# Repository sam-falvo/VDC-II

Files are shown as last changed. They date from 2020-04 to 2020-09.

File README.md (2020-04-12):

# VDC-II
The VDC-II core is an open source Video Display Controller following in the footsteps, but not a pure clone, of the Commodore 8568 VDC chip.

Link to project on [Hackaday.io](https://hackaday.io/project/170581-vdc-ii).

## Why?
I'm working on a homebrew computer of my own design, called the Kestrel-3.
The Kestrel-3 project, however, is very slow-going, as I'm basically building everything from the ground up.
I was asked if I could instead implement the salient bits of the Kestrel-3's video core, the Configurable Graphics Interface Adapter, or CGIA, for the RC2014 backplane.
That would both speed up development of the Kestrel-3 project, as I'm more focused on individual components, but also can benefit the RC2014 community as well.
I said, "that sounds like a great idea!"

Problem is, I've never built an RC2014 or an expansion board for it before.
And, there are many unknowns along the way:
for example, I've never worked with level shifting logic before,
and interfacing a 25MHz dot-clock circuit to the 7MHz bus of the RC2014 will involve multiple clock domains and its respective complexities.
To get my feet wet, I decided to target a design for the 39-pin RC2014 expansion bus using a small FPGA part, specifically the TinyFPGA BX.

The problem with the TinyFPGA BX is that I'm severely I/O limited!
But, with careful interface design, and a constriction on the number of I/O ports accessible to the host CPU, I was able to fit everything into the pins available.
Also, the TinyFPGA BX provides 16KB of block RAM resources, and that sparked a memory: didn't the C128's VDC chip only have 16KB available to it?

Turns out, yes.  And, it also has a constrained host CPU interface as well.
And looking through the C128's Programmers Reference Manual on how to code for the VDC chip,
I saw that much of the CGIA's feature set was already present in the VDC.  Not everything, but most things for sure!
So, I got to thinking, instead of using the CGIA as the basis,
maybe I can create a version of the VDC chip which can drive a VGA monitor, flexibly.
After all,
the [RomWBW HBIOS](https://github.com/wwarthen/RomWBW/blob/master/Source/HBIOS/cvdu.asm)
software already has a VDC driver available for it, so porting software should be much easier.
(Though, strangely, it goes by the name CVDU or Color VDU in the source tree.)
That's the operating theory, at least.

The VDC-II project was born.

## Description
The VDC-II core aims to be a worthy successor to the original Commodore VDC design.
Unlike the original VDC chip, which runs at NTSC frequencies, the VDC-II core is intended to drive a VGA monitor.

While 100% backward compatibility is not my primary goal, I would continue to strive for it where I can afford to.
There will be some features which will simply work differently between the VDC and VDC-II,
such as how horizontal smooth scrolling works.
Some of these incompatibilities will stem naturally from the fact that we're driving a VGA display instead of a CGA display.
**Disclaimer: I do not have a real Commodore 128 to test behavior with.**
I'm limited to comparing behavior against what the Vice `x128` emulator supports.

## Goals
Most importantly, I want to make a VDC-II core that achieves *basic* feature parity with the original VDC.
This should include supporting all 37 of the original register set.
**Note:** Not all bits of all registers will be supported, or will work *exactly* the same way.
For example, the complex interaction between inter-character gaps and horizontal smooth scrolling might compel me to just leave inter-character gaps out of the design.
(Kind of how `x128` does now.)

Going into future day-dreaming mode,
I'd next implement color palette registers,
giving the VDC-II core more color options.
I'd also support an alternative attribute format which allows for both 16 foreground *and* background colors.

The VDC-II core could conceivably be expanded to support sprites as well, perhaps using an interface not unlike the TMS9918A VDP.
This will be very nice for, e.g., supporting mouse pointers and text cursors while in bitmapped mode (e.g., GEOS/128).

## Resources
These are some handy references and resources I've found to help guide my development.
These might be of interest to you as well.

- https://www.retrobrewcomputers.org/lib/exe/fetch.php?media=boards:ecb:cvdu:8563notes.txt
- [Commodore 128 Programmer's Reference Guide](https://www.pagetable.com/?p=620)

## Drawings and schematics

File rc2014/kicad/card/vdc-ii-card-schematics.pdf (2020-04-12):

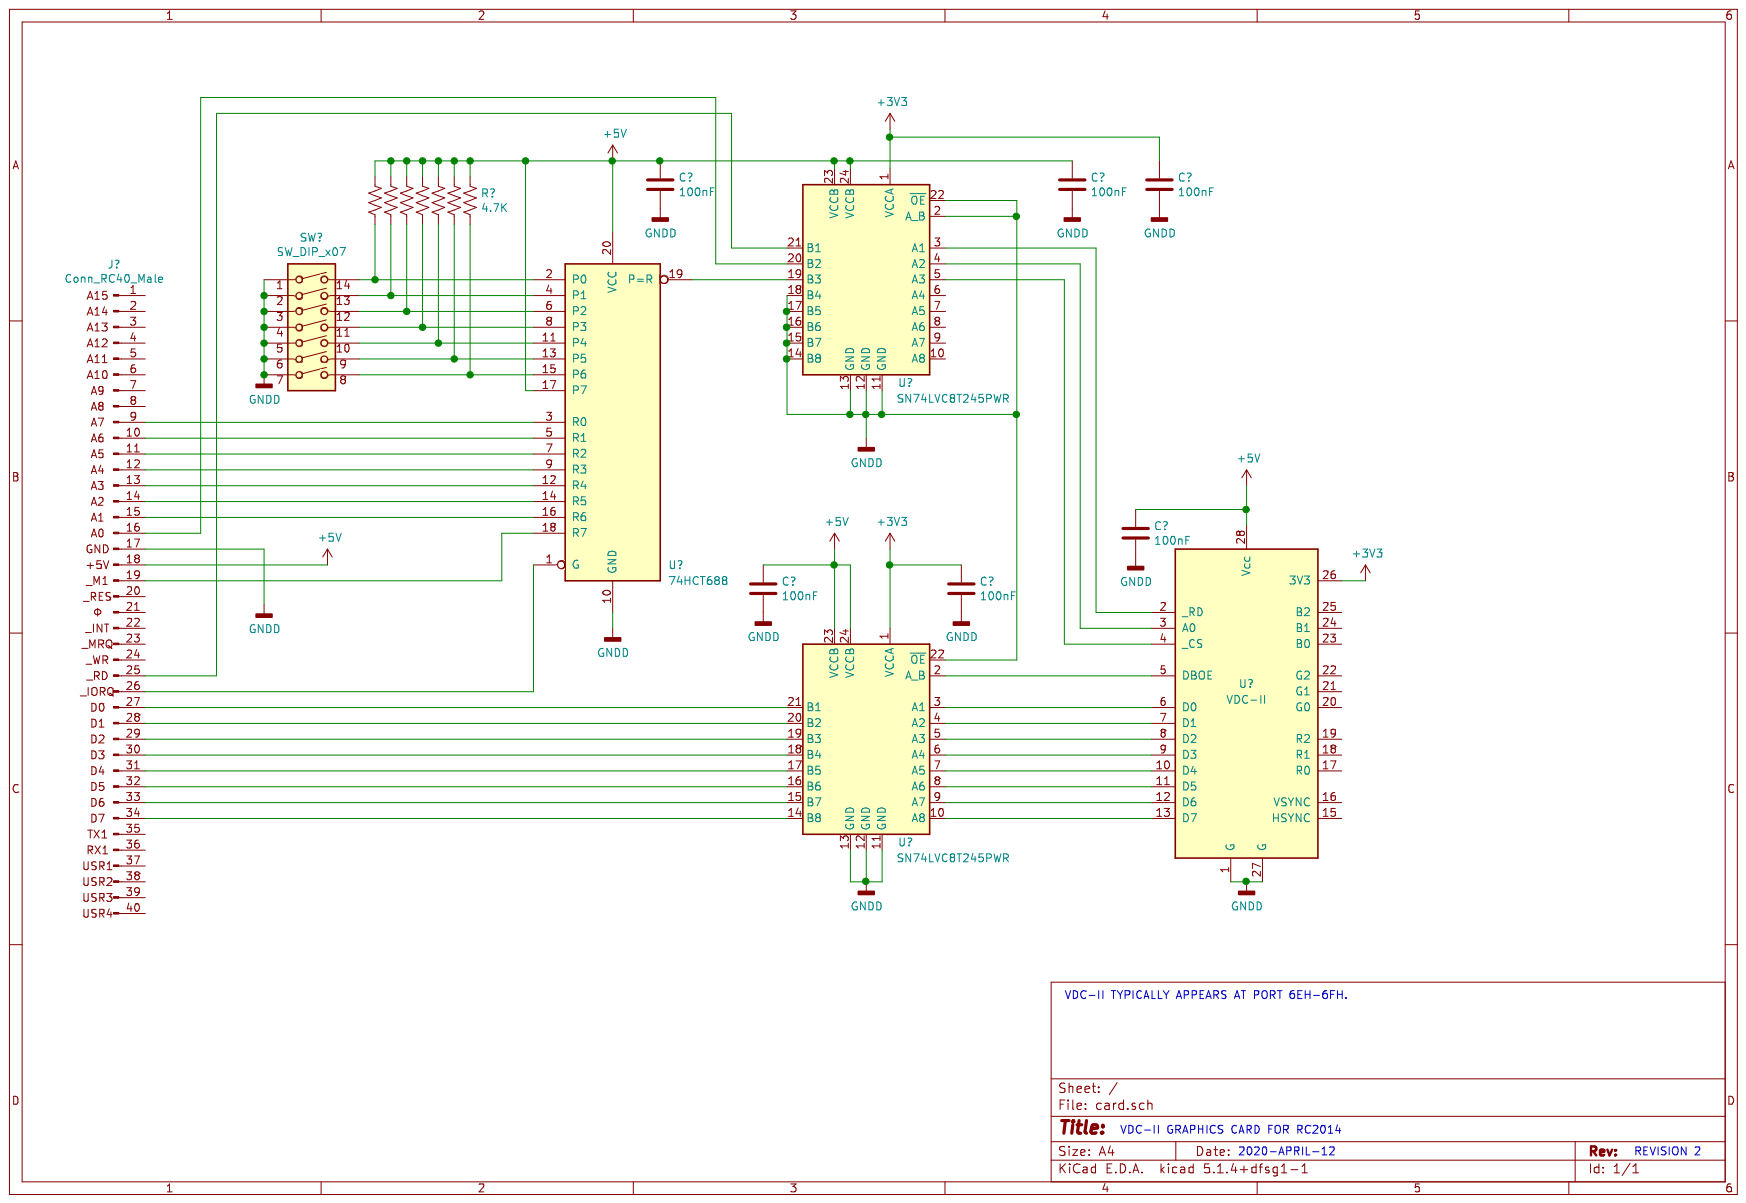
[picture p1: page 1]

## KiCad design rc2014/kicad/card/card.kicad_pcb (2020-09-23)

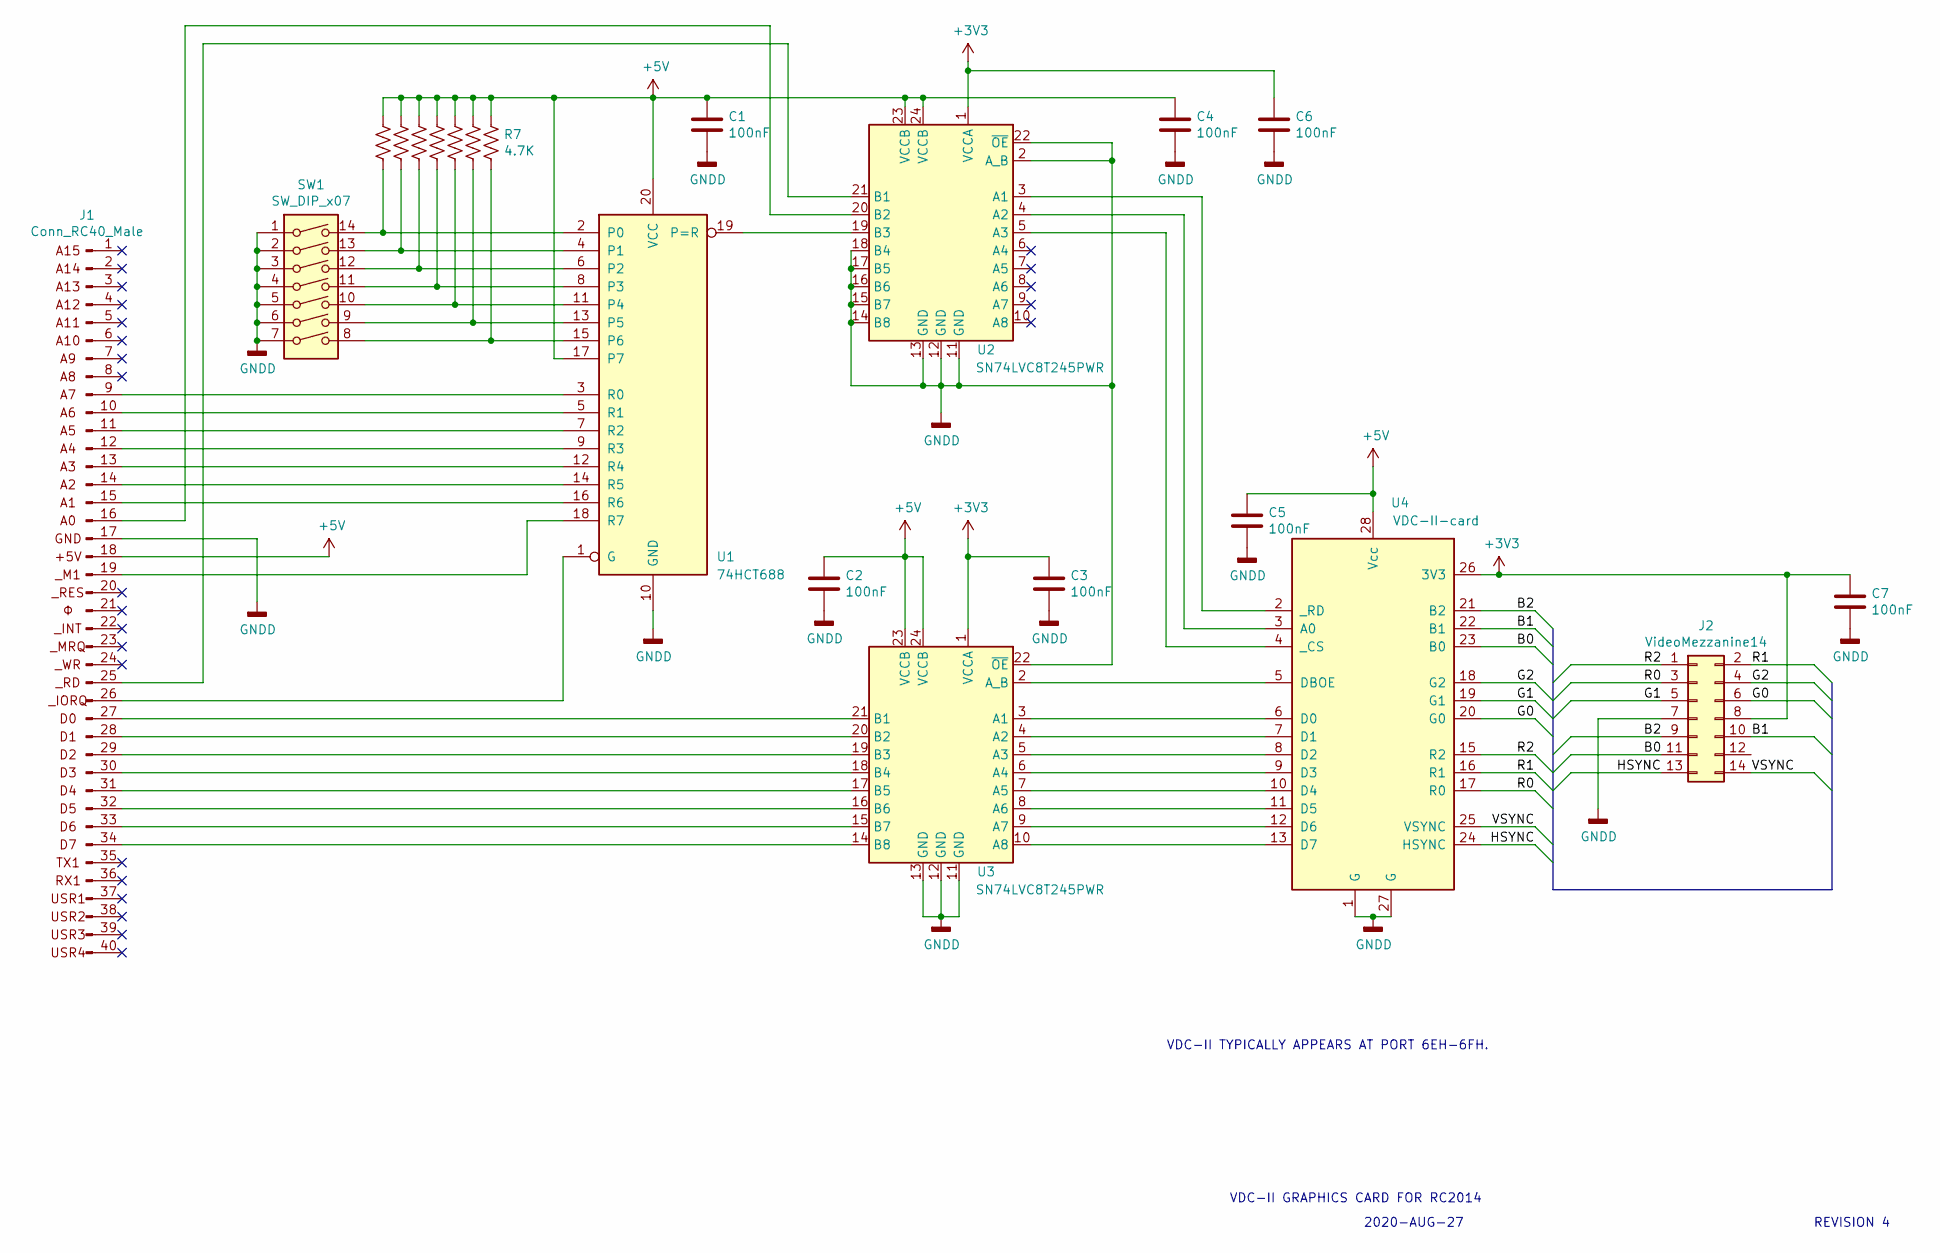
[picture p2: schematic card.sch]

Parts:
C1, C2, C3, C4, C5, C6, C7: 100nF; C_Disc_D6.0mm_W4.4mm_P5.00mm
J1: Conn_RC40_Male; PinHeader_1x40_P2.54mm_Vertical
J2: VideoMezzanine14; PinHeader_2x07_P2.54mm_Vertical
R1, R2, R3, R4, R5, R6, R7: 4.7K; R_Axial_DIN0207_L6.3mm_D2.5mm_P10.16mm_Horizontal
SW1: SW_DIP_x07; SW_DIP_SPSTx07_Slide_9.78x19.96mm_W7.62mm_P2.54mm
U1: 74HCT688; DIP-20_W7.62mm_Socket
U2, U3: SN74LVC8T245PWR; TSSOP-24_4.4x7.8mm_P0.65mm
U4: VDC-II-card; DIP-28_W15.24mm_Socket

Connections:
+3V3: C3.1, C6.1, C7.1, J2.8, U2.1 (VCCA), U3.1 (VCCA), U4.26 (3V3)
+5V: C1.1, C2.1, C4.1, C5.1, J1.18 (+5V), R1.1, R2.1, R3.1, R4.1, R5.1, R6.1, R7.1, U1.17 (P7), U1.20 (VCC), U2.23 (VCCB), U2.24 (VCCB), U3.23 (VCCB), U3.24 (VCCB), U4.28 (Vcc)
/B0: J2.11, U4.23 (B0)
/B1: J2.10, U4.22 (B1)
/B2: J2.9, U4.21 (B2)
/G0: J2.6, U4.20 (G0)
/G1: J2.5, U4.19 (G1)
/G2: J2.4, U4.18 (G2)
/HSYNC: J2.13, U4.24 (HSYNC)
/R0: J2.3, U4.17 (R0)
/R1: J2.2, U4.16 (R1)
/R2: J2.1, U4.15 (R2)
/VSYNC: J2.14, U4.25 (VSYNC)
GNDD: C1.2, C2.2, C3.2, C4.2, C5.2, C6.2, C7.2, J1.17 (GND), J2.7, SW1.1, SW1.2, SW1.3, SW1.4, SW1.5, SW1.6, SW1.7, U1.10 (GND), U2.2 (A_B), U2.11 (GND), U2.12 (GND), U2.13 (GND), U2.14 (B8), U2.15 (B7), U2.16 (B6), U2.17 (B5), U2.18 (B4), U2.22 (~OE), U3.11 (GND), U3.12 (GND), U3.13 (GND), U3.22 (~OE), U4.1 (G), U4.27 (G)
unnamed: J1.9 (A7), U1.3 (R0)
unnamed: J1.10 (A6), U1.5 (R1)
unnamed: J1.11 (A5), U1.7 (R2)
unnamed: J1.12 (A4), U1.9 (R3)
unnamed: J1.13 (A3), U1.12 (R4)
unnamed: J1.14 (A2), U1.14 (R5)
unnamed: J1.15 (A1), U1.16 (R6)
unnamed: J1.16 (A0), U2.20 (B2)
unnamed: J1.19, U1.18 (R7)
unnamed: J1.25, U2.21 (B1)
unnamed: J1.26, U1.1 (G)
unnamed: J1.27, U3.21 (B1)
unnamed: J1.28, U3.20 (B2)
unnamed: J1.29, U3.19 (B3)
unnamed: J1.30, U3.18 (B4)
unnamed: J1.31, U3.17 (B5)
unnamed: J1.32, U3.16 (B6)
unnamed: J1.33, U3.15 (B7)
unnamed: J1.34, U3.14 (B8)
unnamed: R1.2, SW1.14, U1.2 (P0)
unnamed: R2.2, SW1.13, U1.4 (P1)
unnamed: R3.2, SW1.12, U1.6 (P2)
unnamed: R4.2, SW1.11, U1.8 (P3)
unnamed: R5.2, SW1.10, U1.11 (P4)
unnamed: R6.2, SW1.9, U1.13 (P5)
unnamed: R7.2, SW1.8, U1.15 (P6)
unnamed: U1.19 (P=R), U2.19 (B3)
unnamed: U2.3 (A1), U4.2 (_RD)
unnamed: U2.4 (A2), U4.3 (A0)
unnamed: U2.5 (A3), U4.4 (_CS)
unnamed: U3.2 (A_B), U4.5 (DBOE)
unnamed: U3.3 (A1), U4.6 (D0)
unnamed: U3.4 (A2), U4.7 (D1)
unnamed: U3.5 (A3), U4.8 (D2)
unnamed: U3.6 (A4), U4.9 (D3)
unnamed: U3.7 (A5), U4.10 (D4)
unnamed: U3.8 (A6), U4.11 (D5)
unnamed: U3.9 (A7), U4.12 (D6)
unnamed: U3.10 (A8), U4.13 (D7)

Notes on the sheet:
VDC-II GRAPHICS CARD FOR RC2014
REVISION 4
2020-AUG-27
VDC-II TYPICALLY APPEARS AT PORT 6EH-6FH.

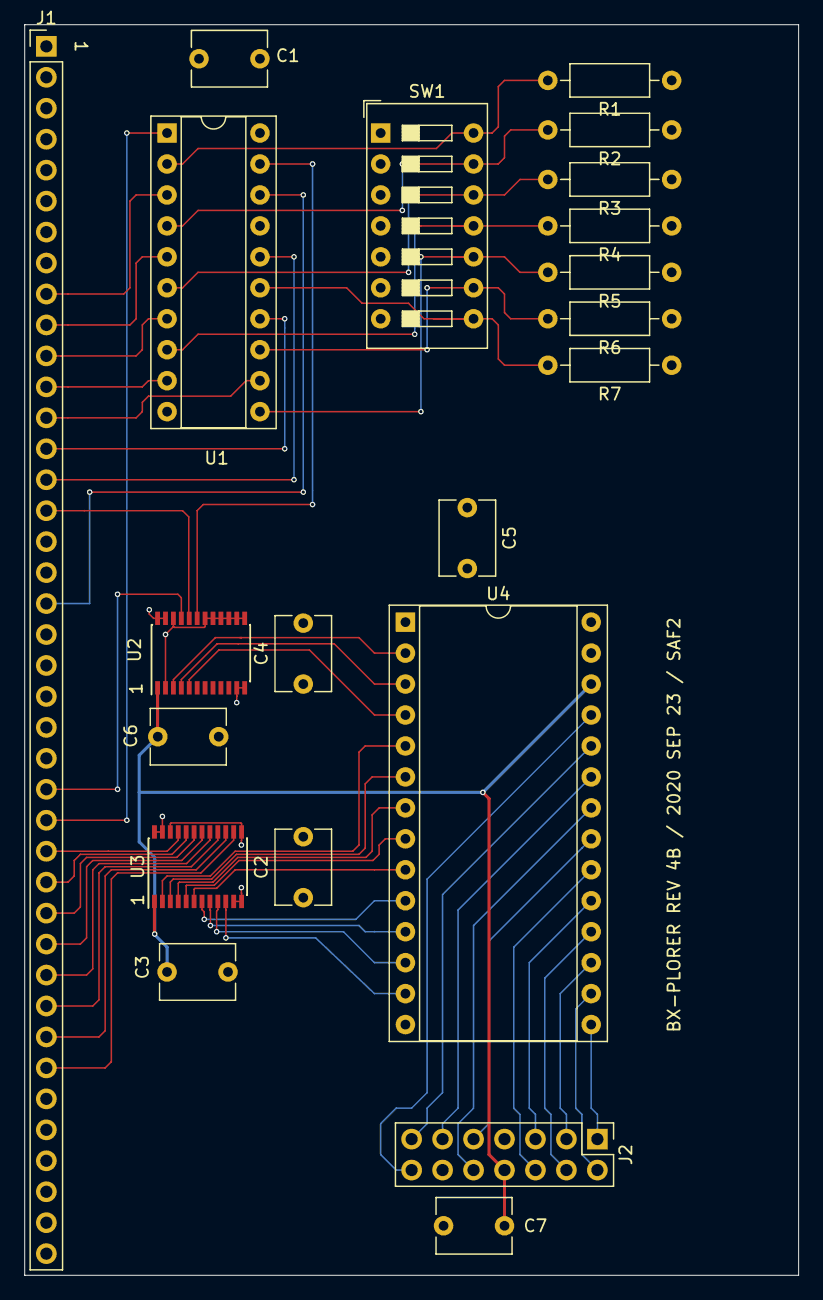
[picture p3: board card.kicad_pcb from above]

Board: 4 copper layers, 63.5 x 102.6 mm, 21 parts (0 on the bottom side), 53 nets.

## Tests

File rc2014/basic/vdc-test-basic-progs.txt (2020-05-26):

;; This buffer is for text that is not saved, and for Lisp evaluation.
;; To create a file, visit it with C-x C-f and enter text in its buffer.

10 DATA 10
200 DATA 0,99

201 DATA 1,80
202 DATA 2,82

203 DATA 3,&h2C
204 DATA 4,31

205 DATA 5,13
206 DATA 6,30

207 DATA 7,31
209 DATA 9,15

222 DATA 22,&h78
1000 READ N

1100 FOR I=1 TO N
1200 PRINT I

1300 READ R,V
1400 OUT &H6E,R

1500 OUT &H6F,V
1600 NEXT I

;; This program listing is to perform a crude memory test
;; on the VDC's video memory.  This program checks to make
;; sure that the VDC is capable of randomly reading data
;; from memory without the MPE's block-operations.

10 PRINT "INITIALIZING"
20 FOR I=0 TO 16383

29 GOSUB 1100
40 OUT 110,31

50 OUT 111,I AND 255
60 GOSUB 1000

70 NEXT I

200 PRINT "TESTING"
210 RANDOMIZE

220 FOR J=0 TO 16384
230 I=INT(RND*16384)

240 GOSUB 1100
250 OUT 110,31

260 K=INP(111)
270 PRINT J,I,I AND 255,K

280 NEXT J
999 END

1000 ZZ=INP(110):IF (ZZ AND 128)=0 THEN 1000
1010 RETURN

1100 OUT 110,18
1110 OUT 111,INT(I/256)

1120 GOSUB 1000
1130 OUT 110,19

1140 OUT 111,I AND 255
1150 GOSUB 1000

1160 RETURN

;; Extension to the above listing which tests block-write functionality.
;; Run with RUN 2000 or some such.

2000 out 110,24
2010 gosub 1000

2020 out 111,0
2030 gosub 1000

2040 for j=0 to &h3F
2050 out 110,18

2060 gosub 1000
2070 out 111,j

2080 gosub 1000
2090 out 110,19

2100 gosub 1000
2110 out 111,0

2120 gosub 1000
2130 out 110,31

2140 gosub 1000
2150 out 111,j

2160 gosub 1000
2170 out 110,30

2180 gosub 1000
2190 out 111,255

2200 gosub 1000
2210 next j

2220 goto 200
270 PRINT J,I,INT(I/256),K

230 i=j

;; HUH...it looks like if I have too many GOSUB 1000s in the code, the block write functionality corrupts video memory in weird ways.  But, if I only have GOSUB 1000s *between* address/data OUTs, it works great!
;; I don't understand why this should be so.  Reading the status register should never affect the operation of the DMA engine.
;; This is a hardware bug which breakds VDC backward compatibility.

;;  The code below exercises block copy.

3000 gosub 1000
3010 out 110,24

3020 out 111,128
3100 for i=&h3C00 to &h3FFF

3110 gosub 1000
3120 gosub 1100

3130 out 110,31
3140 out 111,i and 255

3150 next i

3200 gosub 1000
3210 out 110,18

3220 out 111,0
3230 gosub 1000

3240 out 110,19
3250 out 111,0

3260 gosub 1000
3270 out 110,32

3280 out 111,&h3C
3290 gosub 1000

3300 out 110,33
3310 out 111,0

3320 gosub 1000
3330 out 110,30

3340 out 111,255
3400 goto 200

;;;;;;;;;;;;;;;;;;;;;;;;;;;;;;;;;;;;;
;;
;; The code below is intended to be a file transfer program.
;; A very, very, very slow file transfer program.
;;
;;;;;;;;;;;;;;;;;;;;;;;;;;;;;;;;;;;;;;;

10 PRINT "RECV"
20 PRINT
30 PRINT "PROMPT IS ?"
40 PRINT "Ofilename.ext OPEN"
50 PRINT "C             CLOSE"
60 PRINT "Z...          CODE"
70 PRINT "Q             QUIT"
80 PRINT "?             HELP"
90 PRINT
100 INPUT O$
110 C$=LEFT$(O$,1)
120 IF C$="O" THEN GOTO 1000
130 IF C$="C" THEN GOTO 1100
140 IF C$="Z" THEN GOTO 1200
150 IF C$="Q" THEN END
160 IF C$="?" THEN GOTO 20
170 PRINT "!?"
180 GOTO 100

1000 OPEN "O",1,MID$(O$,2)
1010 GOTO 100

1100 CLOSE 1
1110 GOTO 100

1200 P$=MID$(O$,2)
1210 IF LEN(P$)>16 THEN 1250
1220 PRINT "!L"
1230 GOTO 100
1250 S=0:I=0
1260 H=ASC(MID$(P$,I,1))-64
1265 S=S+H
1270 L=ASC(MID$(P$,I+1,1))-64
1275 S=S+L
1280 B=H*16+L
1290 PRINT#1,CHR$(B);
1300 I=I+2
1310 IF I<17 THEN 1260
1320 S=S AND 15
1330 CK=ASC(MID$(P$,I,1))-64
1340 IF CK=S THEN 100
1350 PRINT "!C"
1360 GOTO 100

;; Example input.  Transmit one line, then wait for ? response.
;; If ! received (or any other character), report error condition and immediately abort transmission.

OTEST.BIN
Z@@@A@B@C@D@E@F@GL
Z@H@I@J@K@L@M@N@OL
ZA@AAABACADAEAFAGD
ZAHAIAJAKALAMANAOD
C
Q

;;
;; Corresponding transmitter program that runs on Linux (under minicom).
;;

#include <stdio.h>
#include <string.h>
#include <inttypes.h>

#include <unistd.h>
#include <termios.h>

static void
error_happened(char *msg) {
	fprintf(stderr, "Error: %s\n", msg);
}

static void
send(FILE *fp) {
	uint8_t buffer[9];
	int checksum, i, h, l, done, size, prompt;

	while(!feof(fp)) {
		memset(buffer, 0, 9);
		size = fread(buffer, 1, 8, fp);
		if(size == 0) {
			if(feof(fp)) break;
			error_happened("file read");
			return;
		} else {
			checksum = 0;

			/* Ask receiver to record 8 bytes */

			printf("Z");
			for(i = 0; i < 8; i++) {
				h = (buffer[i] & 0xF0) >> 4;
				l = (buffer[i] & 0x0F);
				checksum += h+l;
				printf("%c", '@'+h);
				printf("%c", '@'+l);
			}
			printf("%c\r\n", '@'+(checksum & 15));
			fflush(stdout);

			/* Wait for the ? response. */

			prompt = fgetc(stdin);
			if(prompt != '?') {
				error_happened("'? ' expected");
				return;
			}

			prompt = fgetc(stdin);
			if(prompt != ' ') {
				error_happened("'? ' expected");
				return;
			}
		}
	}

	/* Ask receiver to close currently open file. */

	printf("C\r\n");
	fflush(stdout);
}

int
main(int argc, char *argv[]) {
	FILE *fp = NULL;
	struct termios ttysave, ttynonblock;

	// I have no idea if we need this code when run
	// from minicom; it might configure the stdin stream
	// for us.

	tcgetattr(STDIN_FILENO, &ttysave);
	ttynonblock = ttysave;
	ttynonblock.c_lflag &= ~(ICANON | ECHO);
	ttynonblock.c_cc[VMIN] = 1;
	tcsetattr(STDIN_FILENO, TCSANOW, &ttynonblock);

	fp = fopen(argv[1], "rb");
	if(fp) {
		send(fp);
		fclose(fp);
	}

	tcsetattr(STDIN_FILENO, TCSANOW, &ttysave);
}

;; This program is to exercise horizontal smooth scrolling
;; First, we set 128x30 video mode, with 4 pixel wide glyphs
;; and 1 pixel inter-character gap.

10 DATA 12
200 DATA 0,159

201 DATA 1,128
202 DATA 2,131

203 DATA 3,&h2F
204 DATA 4,31

205 DATA 5,13
206 DATA 6,30

207 DATA 7,31
209 DATA 9,15

222 DATA 22,&h43
225 DATA 25,&h04

226 DATA 26,&h93
1000 READ N

1100 FOR I=1 TO N
1200 PRINT I

1300 READ R,V
1400 OUT &H6E,R

1500 OUT &H6F,V
1600 NEXT I

2000 DATA &h43,&h04
2001 DATA &h42,&h03

2002 DATA &h41,&h02
2003 DATA &h40,&h01

2004 DATA &h44,&h00
2010 RESTORE 2000

2020 FOR I=1 TO 5
2030 READ X,Y

2040 OUT &h6E,22
2050 OUT &h6F,X

2060 OUT &h6E,25
2070 OUT &h6F,Y

2080 NEXT I
2090 X=INP(&h6E)

2100 IF (X AND 32)=0 THEN 2090
2110 GOTO 2010

;; This program is a quick and dirty demo for monochrome bitmapped mode.

10 DATA 19
200 DATA 0,99

201 DATA 1,80
202 DATA 2,82

203 DATA 3,&h2C
204 DATA 4,31

205 DATA 5,13
206 DATA 6,30

207 DATA 7,31
209 DATA 9,15

212 DATA 12,0
213 DATA 13,0

220 DATA 20,&h20
221 DATA 21,&h00

222 DATA 22,&h78
223 DATA 23,&h0F

224 DATA 24,0
225 DATA 25,&h87

226 DATA 26,&hF1
228 DATA 28,&h20

1000 READ N
1100 FOR I=1 TO N

1200 PRINT I
1300 READ R,V

1400 OUT &H6E,R
1500 OUT &H6F,V

1600 NEXT I

	Draw a 640x200 50% grey stipple

2000 OUT 110,18
2010 OUT 111,0

2020 GOSUB 3000

2030 OUT 110,19
2040 OUT 111,0

2050 GOSUB 3000

2060 OUT 110,31
2070 OUT 111,&hAA

2080 GOSUB 3000

2090 OUT 110,30
2100 OUT 111,79

2110 GOSUB 3000

2120 OUT 110,31
2130 OUT 111,&h55

2140 GOSUB 3000

2150 OUT 110,30
2160 OUT 111,79

2170 GOSUB 3000

2180 OUT 110,18
2190 OUT 111,0

2200 GOSUB 3000

2210 OUT 110,19
2220 OUT 111,160

2230 GOSUB 3000

2240 OUT 110,32
2250 OUT 111,0

2260 OUT 110,33
2270 OUT 111,0

2280 OUT 110,24
2290 OUT 111,INP(111) OR 128

2300 FOR Y=1 TO 49
2310 OUT 110,30

2320 OUT 111,160
2330 GOSUB 3000

2340 NEXT Y
2999 END

3000 IF INP(110) AND 128 = 0 THEN 3000
3010 RETURN

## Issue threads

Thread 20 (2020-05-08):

Block write/copy fail to function consistently under certain usage patterns.

sam-falvo, 2020-05-08:
If you were to type in the following program in MBASIC on the RC2014 and invoke it with `RUN 2000`, the results of the block write test will show corrupted video memory.  Evidence suggests that the DMA engine can sometimes cause more than 255 bytes to be written, which is not supposed to happen.

```
10 PRINT "INITIALIZING"
20 FOR I=0 TO 16383
30 GOSUB 1100
40 OUT 110,31
50 OUT 111,I AND 255
60 GOSUB 1000
70 NEXT I

200 PRINT "TESTING"
210 RANDOMIZE

220 FOR J=0 TO 16384
230 I=J
240 GOSUB 1100
250 OUT 110,31
260 K=INP(111)
270 PRINT J,I,INT(I/256),K
280 NEXT J
999 END

1000 ZZ=INP(110):IF (ZZ AND 128)=0 THEN 1000
1010 RETURN

1100 OUT 110,18
1110 OUT 111,INT(I/256)
1120 GOSUB 1000
1130 OUT 110,19
1140 OUT 111,I AND 255
1150 GOSUB 1000
1160 RETURN

2000 out 110,24
2010 gosub 1000
2020 out 111,0
2030 gosub 1000
2040 for j=0 to &h3F
2050 out 110,18
2060 gosub 1000
2070 out 111,j
2080 gosub 1000
2090 out 110,19
2100 gosub 1000
2110 out 111,0
2120 gosub 1000
2130 out 110,31
2140 gosub 1000
2150 out 111,j
2160 gosub 1000
2170 out 110,30
2180 gosub 1000
2190 out 111,255
2200 gosub 1000
2210 next j
2220 goto 200
```
However, if you were to alter the program above to use the following code instead, where you only wait for the ready status flag _after you commence an operation or write a register's data port_, then everything works perfectly as it should.
```
2000 gosub 1000
2010 out 110,24
2020 out 111,0
2040 for j=0 to &h3F
2050 gosub 1000
2060 out 110,18
2070 out 111,j
2080 gosub 1000
2090 out 110,19
2110 out 111,0
2120 gosub 1000
2130 out 110,31
2150 out 111,j
2160 gosub 1000
2170 out 110,30
2190 out 111,255
2210 next j
2220 goto 200
```
It's not clear to me why checking the ready flag in the status register should interfere with the MPE; yet, it appears to do exactly that.

This is a **low-priority** bug; I believe this breaks compatibility with Commodore 8563 VDC behavior, since per Commodore's documentation, you're supposed to poke an address, **then wait for the ready flag to assert,** then poke data.  Instead, VDC-II appears to strongly prefer poking an address, then poking data, **and then waiting for the ready flag.**  Note the difference in order of operations.

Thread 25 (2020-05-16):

VDC-II needs to support monochrome bitmapped graphics.

sam-falvo, 2020-05-16:
- [ ] 200V/240V resolution with line-doubling
- [ ] 200V/240V resolution with interstitial blanked lines (emulating non-interlaced NTSC CRT displays)
- [ ] 400V/480V resolution

sam-falvo, 2020-05-16:
Address Generator State Machine
```
| State | GO_I | STALL_I | GO_FONT_I | AE_I | BM_I | ADR_O    | STB_O | Next | INCATRPTR | INCCHRPTR | PADR |
|-------+------+---------+-----------+------+------+----------+-------+------+-----------+-----------+------|
| IDLE  |    0 |         |           |      |      | -        |     0 | IDLE |         0 |         0 |      |
| IDLE  |    1 |         |           |    0 |      | -        |     0 | C1   |         0 |         0 |      |
| IDLE  |    1 |         |           |    1 |      | -        |     0 | A1   |         0 |         0 |      |
|-------+------+---------+-----------+------+------+----------+-------+------+-----------+-----------+------|
| A1    |      |       0 |           |      |      | ATRPTR   |     1 | A2   |         1 |         0 |      |
| A1    |      |       1 |           |      |      | ATRPTR   |     1 | A1   |         0 |         0 |      |
| A2    |      |       0 |           |      |      | ATRPTR   |     1 | A3   |         1 |         0 |      |
| A2    |      |       1 |           |      |      | ATRPTR   |     1 | A2   |         0 |         0 |      |
| A3    |      |       0 |           |      |      | ATRPTR   |     1 | A4   |         1 |         0 |      |
| A3    |      |       1 |           |      |      | ATRPTR   |     1 | A3   |         0 |         0 |      |
| A4    |      |       0 |           |      |      | ATRPTR   |     1 | C1   |         1 |         0 |      |
| A4    |      |       1 |           |      |      | ATRPTR   |     1 | A4   |         0 |         0 |      |
|-------+------+---------+-----------+------+------+----------+-------+------+-----------+-----------+------|
| C1    |      |       0 |           |      |      | CHRPTR   |     1 | C2   |         0 |         1 |      |
| C1    |      |       1 |           |      |      | CHRPTR   |     1 | C1   |         0 |         0 |      |
| C2    |      |       0 |           |      |      | CHRPTR   |     1 | C3   |         0 |         1 |      |
| C2    |      |       1 |           |      |      | CHRPTR   |     1 | C2   |         0 |         0 |      |
| C3    |      |       0 |           |      |      | CHRPTR   |     1 | C4   |         0 |         1 |      |
| C3    |      |       1 |           |      |      | CHRPTR   |     1 | C3   |         0 |         0 |      |
| C4    |      |       0 |           |      |    0 | CHRPTR   |     1 | F1   |         0 |         1 |      |
| C4    |      |       0 |           |      |    1 | CHRPTR   |     1 | IDLE |         0 |         1 |      |
| C4    |      |       1 |           |      |      | CHRPTR   |     1 | C4   |         0 |         0 |      |
|-------+------+---------+-----------+------+------+----------+-------+------+-----------+-----------+------|
| F1    |      |         |         0 |      |      | FONT(C1) |     0 | F1   |         0 |         0 |    0 |
| F1    |      |       0 |         1 |      |      | FONT(C1) |     1 | F2   |         0 |         0 |    0 |
| F1    |      |       1 |         1 |      |      | FONT(C1) |     1 | F1   |         0 |         0 |    0 |
| F2    |      |       0 |           |      |      | FONT(C2) |     1 | F3   |         0 |         0 |    1 |
| F2    |      |       1 |           |      |      | FONT(C2) |     1 | F2   |         0 |         0 |    1 |
| F3    |      |       0 |           |      |      | FONT(C3) |     1 | F4   |         0 |         0 |    2 |
| F3    |      |       1 |           |      |      | FONT(C3) |     1 | F3   |         0 |         0 |    2 |
| F4    |      |       0 |           |      |      | FONT(C4) |     1 | IDLE |         0 |         0 |    3 |
| F4    |      |       1 |           |      |      | FONT(C4) |     1 | F4   |         0 |         0 |    3 |
|-------+------+---------+-----------+------+------+----------+-------+------+-----------+-----------+------|
```

Data Receiver State Machine
```
| State | GO_I | AE_I | BM_I | ACK_I | CYC_O | Next | WADR | AWE | CWE | GO_FONT_O |
|-------+------+------+------+-------+-------+------+------+-----+-----+-----------|
| IDLE  |    0 |      |      |       |     0 | IDLE |      |   0 |   0 |         0 |
| IDLE  |    1 |    0 |      |       |     0 | C1   |      |   0 |   0 |         0 |
| IDLE  |    1 |    1 |      |       |     0 | A1   |      |   0 |   0 |         0 |
|-------+------+------+------+-------+-------+------+------+-----+-----+-----------|
| A1    |      |      |      |     0 |     1 | A1   |    0 |   0 |   0 |         0 |
| A1    |      |      |      |     1 |     1 | A2   |    0 |   1 |   0 |         0 |
| A2    |      |      |      |     0 |     1 | A2   |    1 |   0 |   0 |         0 |
| A2    |      |      |      |     1 |     1 | A3   |    1 |   1 |   0 |         0 |
| A3    |      |      |      |     0 |     1 | A3   |    2 |   0 |   0 |         0 |
| A3    |      |      |      |     1 |     1 | A4   |    2 |   1 |   0 |         0 |
| A4    |      |      |      |     0 |     1 | A4   |    3 |   0 |   0 |         0 |
| A4    |      |      |      |     1 |     1 | C1   |    3 |   1 |   0 |         0 |
|-------+------+------+------+-------+-------+------+------+-----+-----+-----------|
| C1    |      |      |      |     0 |     1 | C1   |    0 |   0 |   0 |         0 |
| C1    |      |      |      |     1 |     1 | C2   |    0 |   0 |   1 |         0 |
| C2    |      |      |      |     0 |     1 | C2   |    1 |   0 |   0 |         0 |
| C2    |      |      |      |     1 |     1 | C3   |    1 |   0 |   1 |         0 |
| C3    |      |      |      |     0 |     1 | C3   |    2 |   0 |   0 |         0 |
| C3    |      |      |      |     1 |     1 | C4   |    2 |   0 |   1 |         0 |
| C4    |      |      |      |     0 |     1 | C4   |    3 |   0 |   0 |         0 |
| C4    |      |      |    0 |     1 |     1 | F1   |    3 |   0 |   1 |         0 |
| C4    |      |      |    1 |     1 |     1 | IDLE |    3 |   0 |   1 |         0 |
|-------+------+------+------+-------+-------+------+------+-----+-----+-----------|
| F1    |      |      |      |     0 |     1 | F1   |    0 |   0 |   0 |         1 |
| F1    |      |      |      |     1 |     1 | F2   |    0 |   0 |   1 |         1 |
| F2    |      |      |      |     0 |     1 | F2   |    1 |   0 |   0 |         0 |
| F2    |      |      |      |     1 |     1 | F3   |    1 |   0 |   1 |         0 |
| F3    |      |      |      |     0 |     1 | F3   |    2 |   0 |   0 |         0 |
| F3    |      |      |      |     1 |     1 | F4   |    2 |   0 |   1 |         0 |
| F4    |      |      |      |     0 |     1 | F4   |    3 |   0 |   0 |         0 |
| F4    |      |      |      |     1 |     1 | IDLE |    3 |   0 |   1 |         0 |
|-------+------+------+------+-------+-------+------+------+-----+-----+-----------|
```

Closed 2020-05-26.

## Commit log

2020-03-21 Hsync module (#2)
    * Fixes #1. HSYNC generation circuit.
    * Refactor
    * Add test for prover
    * refactor again
    * Refactor again.
    * Remove dead code
    * Remove dead code
2020-03-25 Z80 bus interface. Fixes #7. (#8)
    * Initial skeleton for Host Bus module.
    * Output enable driver control for data bus
    * This completes the Z80 host processor bus interface.
    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
2020-03-30 Pll (#13)
    * PLL and reworked I/O to match physical wiring.
    * New pin assignment.
    * Forgot to add pll.py
2020-03-30 KiCAD schematics for current test hardware
    [card.kicad_pcb, card.sch]
2020-04-12 Revision 2 w/ new level shifters
    [card.sch]
2020-04-19 Switch from count-up to count-down character counter.
    The VDC appears to use down-counters for triggering events, such as
    flagging when to start shifting dots to teh screen, even though some
    registers (e.g., light-pen) appear to make use of up-counters. I don't
    anticipate using light-pens with the VDC-II (though the registers will
    remain reserved for future restoration of the facility if someone wants
    it). Therefore, switching to using down-counters optimizes for the more
    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
2020-04-25 This should complete the VSYNC interface.
    In addition to generating both HSYNC and VSYNC, this circuit should also
    drive the display with a test pattern which illustrates where character
    cells reside on the playfield.
2020-04-25 Vsync (#17). Fixes #15
    * Switch from count-up to count-down character counter.
    common case.
    I think.
    VDC documentation can be pretty confusing at times, and low-level
    descriptions of the VDC seems to simply not exist.
    * Yet another sync generator.
    This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
2020-05-30 User environment framework for clock demo
2020-06-16 First cut at VDC-Forth
2020-08-28 R4 schematic for VDC-II card
    [card.sch]
2020-08-28 Repin U4
    [card.kicad_pcb, card.sch]
2020-08-28 Finish PCB layout for main PP board
    [card.kicad_pcb, card.sch]
2020-08-29 Small revisions to make things work for OSHPark.
    [card.kicad_pcb]
2020-09-23 Rev 4B of PCB layout.
    - Fix missing pin 1 indicators.
    - Fix missing 3.3V supply connection on U2.
    - Fix DIP switch footprint size.
    - Rename PCB to BX-PLORER
    - Pixel Pusher will be (BX-PLORER + VGA mezzanine).
    - Separate mezzanine planned for PS/2 keyboard and mouse.
    - Convert J2 from 14-pin DIP to 14-pin female header. (Same pinout
    though.)
    [card.kicad_pcb, card.sch]
